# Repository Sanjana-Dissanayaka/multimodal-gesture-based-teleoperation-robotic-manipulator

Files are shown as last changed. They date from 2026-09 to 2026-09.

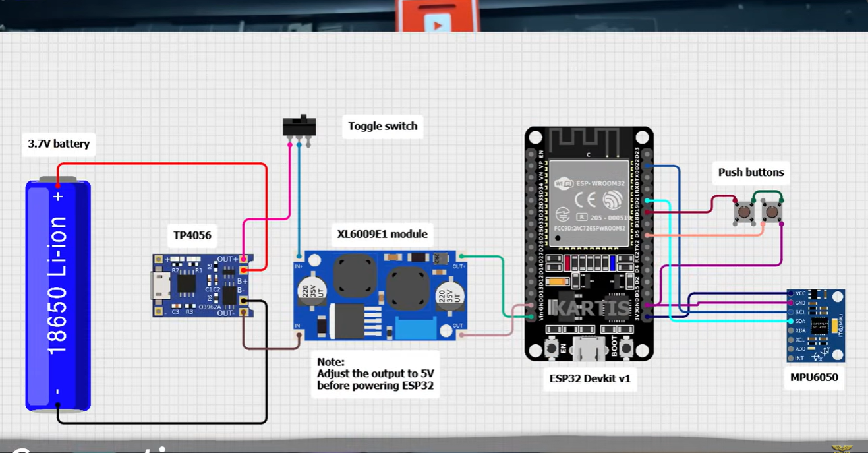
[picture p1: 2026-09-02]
Screenshot 2026-06-09 132017.png

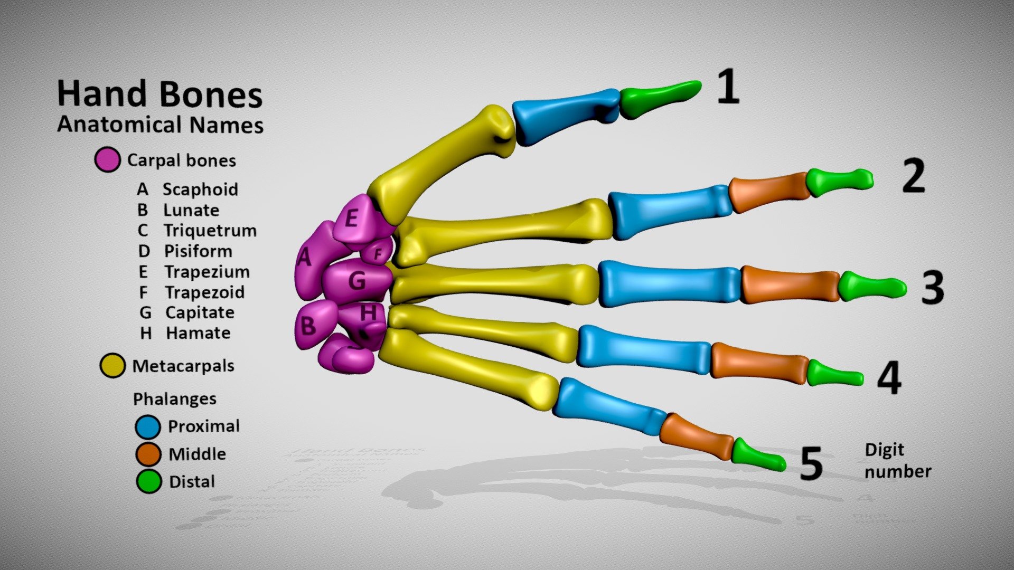
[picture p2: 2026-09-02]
77d40d91b67f4126b4f3d04fdb017b0f.jpeg

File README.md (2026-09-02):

# Multimodal Gesture-Based Teleoperation Framework for Low-Cost Robotic Manipulators

A low-cost gesture-based robotic teleoperation framework designed to provide an intuitive human–robot interaction interface using a wearable sensor glove.

The current system combines an **MPU6050 inertial measurement unit (IMU)** and **flex sensors** with calibration, filtering, gesture recognition, VPython hand visualization, and inverse-kinematics-based robotic manipulator control.

The framework is being extended toward a **hybrid multimodal teleoperation system** by integrating computer-vision-based hand tracking and physical robotic manipulator validation.

---

## Project Overview

Conventional robotic manipulator teleoperation interfaces such as joysticks and teach pendants can be less intuitive when operators need to perform natural hand-based manipulation.

Gesture-based interfaces provide a more natural method of communicating human intent to a robotic system. However, systems that depend on only one sensing method may experience problems such as:

* Sensor drift
* Measurement noise
* Camera occlusion
* Lighting variation
* Limited gesture information
* High implementation cost
* Reduced teleoperation accuracy

This project investigates a low-cost teleoperation framework that initially uses a wearable **IMU + flex-sensor glove** and is designed to later combine wearable sensing with computer vision.

---

## Overall Objective

Develop and validate a low-cost hybrid teleoperation system that integrates an **IMU + flex-sensor glove** with computer-vision-based hand tracking to achieve robust, accurate, and intelligent robotic manipulator control.

---

## System Architecture





The current teleoperation pipeline can be represented as:

```text
Human Hand
    │
    ▼
IMU + Flex Sensor Glove
    │
    ▼
Microcontroller / Data Acquisition
    │
    ▼
Calibration + Filtering
    │
    ▼
Gesture Recognition + Orientation Estimation
    │
    ├──────────────► VPython Virtual Hand
    │
    ▼
Gesture / Orientation Command Mapping
    │
    ▼
Inverse Kinematics
    │
    ▼
Robotic Manipulator Simulation
    │
    ▼
Sorting / Pick-and-Place Tasks
```

The planned multimodal extension is:

```text
Wearable Sensor Glove ──────┐
                            │
                            ▼
                    Hybrid Sensor Fusion
                            ▲
                            │
RGB Camera + MediaPipe ─────┘
                            │
                            ▼
                Robotic Manipulator Control
```

---

## Current Implementation

### 1. Wearable Sensing Layer

The wearable glove provides information about hand orientation and finger movement.

**MPU6050 IMU**

Used to estimate:

* Roll
* Pitch
* Yaw

**Flex Sensors**

Used to detect:

* Finger bending
* Open-hand gestures
* Closed-hand gestures
* Finger-count gestures
* Object-selection commands

---

## 2. Sensor Acquisition and Stabilization



Raw sensor data can contain noise, offsets, and small fluctuations.

The system therefore applies:

* Startup neutral calibration
* Flex-sensor calibration
* IMU calibration
* Deadband processing
* First-order smoothing
* Gesture stabilization
* Threshold-based gesture classification

These techniques improve the stability of commands before they are transmitted to the robotic manipulator.

---

## 3. Flex-Sensor Gesture Validation

The current gesture-validation criteria include:

| Condition | Approximate Threshold |
| --- | ---: |
| Straight finger | ≤ 25° |
| Bent finger | ≥ 60° |
| Stable gesture hold | 0.5 s |

A gesture must remain sufficiently stable before it is accepted as a control command.

This helps prevent accidental commands caused by temporary sensor fluctuations.

---

## 4. Gesture Mapping

Finger gestures are mapped to object-selection and manipulation commands.

| Gesture | Command |
| --- | --- |
| 1 finger  | Select RED object |
| 2 fingers | Select BLUE object |
| 3 fingers | Select GREEN object  |
| 4 fingers | Select YELLOW object |
| Fist | PICK |
| Open palm | PLACE / RELEASE |

This allows the operator to select and manipulate objects using natural hand gestures.

---

## 5. IMU Orientation Mapping

The MPU6050 provides orientation information for controlling the manipulator end effector.

| Human-Hand Motion | Robot Command |
| --- | --- |
| Roll | End-effector roll  |
| Pitch | End-effector pitch |
| Yaw | End-effector yaw |

Control limits are applied to prevent unrealistic or unstable manipulator commands.

### Current Safety Limits

| Motion | Limit |
| --- | ----: |
| Roll |  ±35° |
| Pitch |  ±35° |
| Yaw |  ±60° |
| Command rate | 25 Hz |

---

## 6. Virtual Hand Validation

Before controlling the robotic manipulator, sensor information is visualized using **VPython**.

The virtual-hand environment is used to validate:

* Finger bending
* Hand orientation
* Open-palm detection
* Fist detection
* Finger-count gestures
* Sensor calibration
* Gesture stability

This provides an intermediate validation stage between the physical glove and robotic manipulator.

---

## 7. Robotic Manipulator Simulation

Robotic manipulation is investigated using simulation environments such as:

* PyBullet
* CoppeliaSim

The simulation stage includes:

* Manipulator kinematics
* Forward kinematics
* Inverse kinematics
* End-effector orientation control
* Gesture-to-command mapping
* Object selection
* Pick-and-place operations
* Object sorting
* Contact-based manipulation experiments

---

## Inverse Kinematics

The desired end-effector pose generated from the gesture interface is converted into manipulator joint commands using inverse kinematics.

The general control process is:

```text
Human Gesture
      ↓
Target End-Effector Pose
      ↓
Inverse Kinematics
      ↓
Required Joint Angles
      ↓
Manipulator Motion
```

Inverse kinematics allows intuitive hand commands to be translated into feasible robotic manipulator movements.

---

## Hardware

The project hardware platform includes or investigates:

* MPU6050 IMU
* Flex sensors
* Wearable glove
* Microcontroller
* Custom PCB
* CH340G USB communication interface
* Flex-sensor interface circuitry
* Sensor wiring and connectors
* Robotic manipulator for final physical testing
* RGB camera for the planned vision stage

---

## Software and Development Tools

### Current Tools

* Python
* VPython
* PyBullet
* CoppeliaSim
* Arduino IDE
* KiCad
* Git
* GitHub

### Planned Vision Tools

* OpenCV
* MediaPipe

### Analysis and Evaluation

* Python
* MATLAB

---

## Major Development Phases

### Phase 1 – Wearable Hardware Development

* System architecture development
* PCB design
* Embedded firmware
* Hardware integration

### Phase 2 – Sensor Acquisition and Calibration

* MPU6050 calibration
* Flex-sensor calibration
* Noise filtering
* Gesture stabilization
* Wearable glove fabrication

### Phase 3 – Virtual Hand and Manipulator Validation

* VPython visualization
* Gesture mapping
* Teleoperation data acquisition
* Manipulator simulation
* Inverse-kinematics control

### Phase 4 – Vision-Based Teleoperation

Planned development includes:

* MediaPipe hand tracking
* Vision gesture recognition
* Vision-only manipulator control
* Performance comparison with the sensor glove

### Phase 5 – Hybrid Sensor Fusion

The future multimodal framework will combine:

```text
IMU
 +
Flex Sensors
 +
Computer Vision
        ↓
Hybrid Gesture Estimation
        ↓
Robotic Manipulator Control
```

The aim is to improve robustness against problems such as sensor drift and camera occlusion.

### Phase 6 – Physical Robot Integration

The final stage is intended to include:

* Physical robotic manipulator integration
* Wireless master–slave communication
* Servo-control optimization
* Real-time physical teleoperation
* Pick-and-place experiments
* Robustness testing
* Latency measurement
* Trajectory analysis
* Statistical evaluation

---

## Key Features

* Low-cost wearable gesture interface
* MPU6050-based hand orientation estimation
* Flex-sensor finger-motion measurement
* Sensor calibration
* Deadband processing
* Signal smoothing
* Stable gesture detection
* VPython virtual-hand visualization
* Gesture-labelled object selection
* Inverse-kinematics-based manipulator control
* PyBullet/CoppeliaSim simulation
* Pick-and-place control
* Object sorting
* Extendable multimodal architecture
* Planned MediaPipe computer-vision integration
* Designed for physical robotic-manipulator validation

---

## Research Contribution

The current framework provides a practical foundation for an intuitive and cost-effective human–robot teleoperation interface.

The main research direction is the development of a multimodal system that combines the advantages of wearable sensors and computer vision.

Potential benefits include:

* Improved teleoperation robustness
* Reduced dependence on conventional joysticks
* Natural human–robot interaction
* Improved resistance to camera occlusion
* Compensation for wearable-sensor drift
* Low implementation cost
* Flexible gesture-to-robot mapping

---

---
 ## Project Status

### Completed / Demonstrated

* Wearable gesture-glove prototype
* MPU6050 sensor acquisition
* Flex-sensor acquisition
* Sensor calibration
* Signal smoothing and deadband
* Gesture recognition
* VPython virtual-hand visualization
* Gesture-to-command mapping
* Manipulator simulation
* Inverse-kinematics-based control
* Gesture-controlled sorting and pick-and-place demonstrations

### Next Development Stage

* RGB-camera integration
* MediaPipe hand tracking
* Vision-only teleoperation
* Comparison between glove and vision systems
* Hybrid sensor fusion
* Physical robotic manipulator integration
* Experimental performance evaluation

---

## Future Improvements

* MediaPipe hand-landmark tracking
* Adaptive multimodal sensor fusion
* Vision and wearable-sensor synchronization
* Automatic sensor-drift compensation
* Kalman or complementary filtering
* Improved gesture-classification algorithms
* Wireless glove communication
* Physical 6-DoF manipulator integration
* End-effector camera feedback
* Collision avoidance
* Workspace constraints
* Trajectory smoothing
* Latency optimization
* Gesture confusion-matrix analysis
* Quantitative trajectory-error analysis
* User-based teleoperation experiments

---

## Contributors

### Lowe W.N.D.

**Registration No.: 2022/E/172**

Primary areas include:

* Embedded electronics
* PCB development
* IMU and flex-sensor calibration
* Python development
* Sensor fusion
* Teleoperation implementation
* Experimental evaluation

### Dissanayaka W.A.M.S.K.

**Registration No.: 2022/E/174**

Primary areas include:

* VPython visualization
* PyBullet simulation
* Computer vision
* MediaPipe implementation
* Mechanical fabrication
* Sensor-fusion development
* Experimental evaluation
* Documentation

---

## Supervisors

**Supervisor:** Mr. M. Barathraj
**Co-Supervisor:** Mr. P. Ravivarman

Department of Electrical & Electronic Engineering
Faculty of Engineering
University of Jaffna

---

## License

An open-source license has not yet been specified for this research project.

Because the repository contains collaborative university research work, an appropriate license should be selected only after agreement among the project contributors and relevant supervisors.

---

## Acknowledgements

This project is being developed as part of the undergraduate research work of the **Department of Electrical & Electronic Engineering, Faculty of Engineering, University of Jaffna**.

The authors acknowledge the guidance and support provided by the project supervisor and co-supervisor throughout the development of the gesture-based robotic teleoperation framework.

---

**Project:** Gesture-Based Teleoperation of a Robotic Manipulator
**Research Direction:** Low-Cost Hybrid Gesture-Based Teleoperation Using Wearable Sensor Fusion and Computer Vision

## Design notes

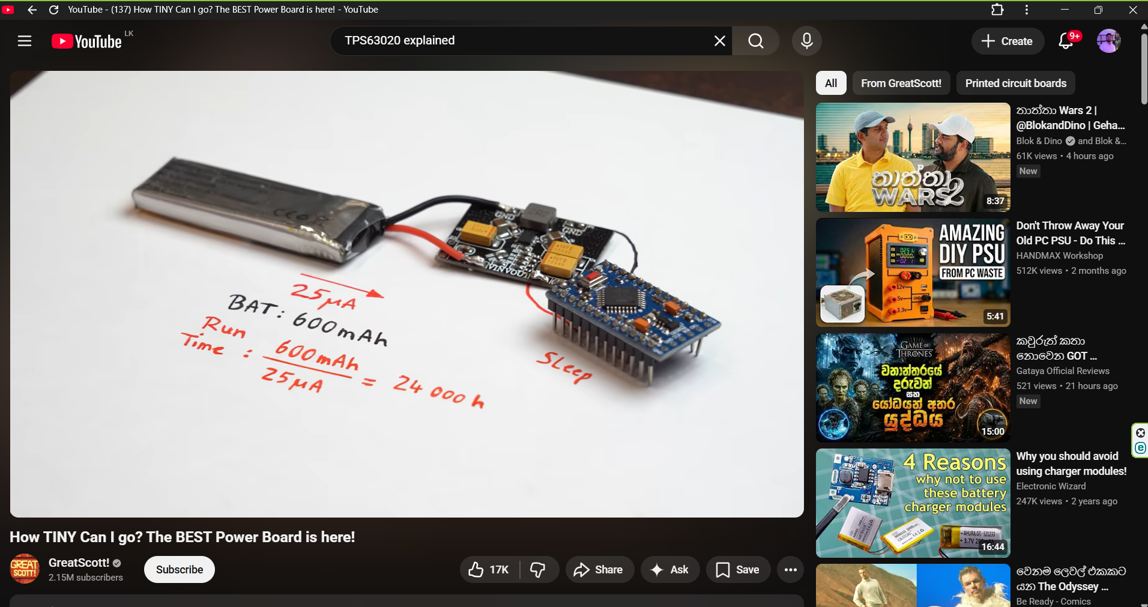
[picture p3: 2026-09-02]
Screenshot 2026-06-09 135950.png

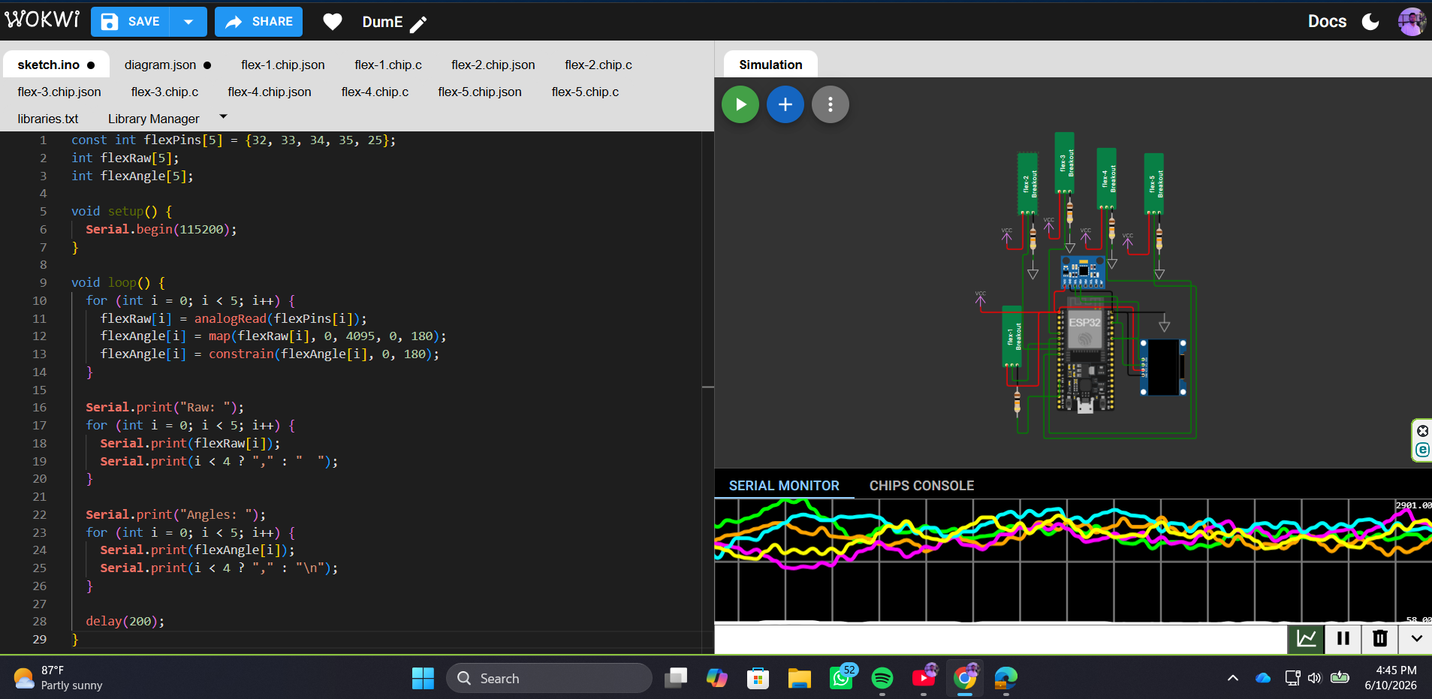
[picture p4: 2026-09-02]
FIVE_FLEX.png

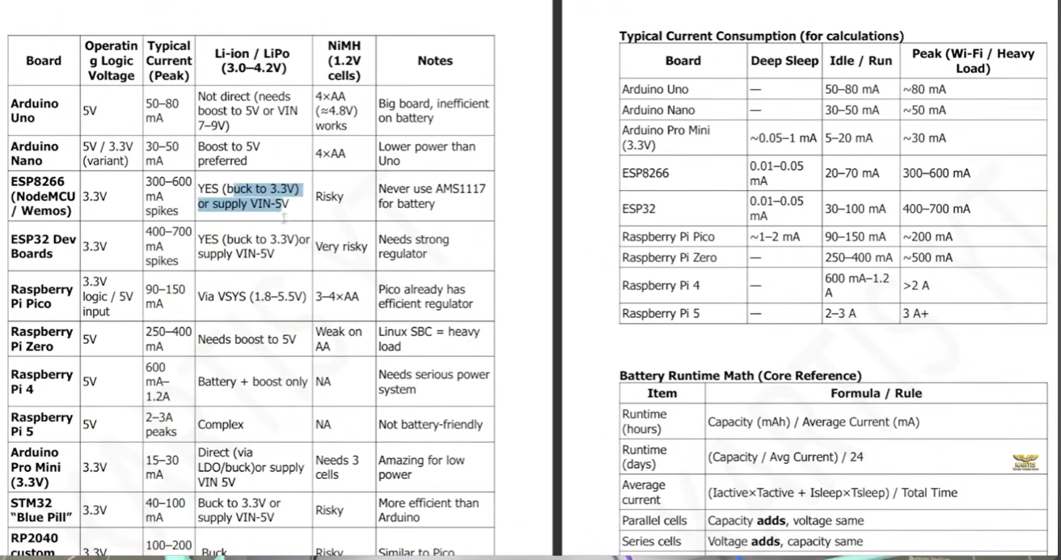
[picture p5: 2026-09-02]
Screenshot 2026-06-09 132211.png

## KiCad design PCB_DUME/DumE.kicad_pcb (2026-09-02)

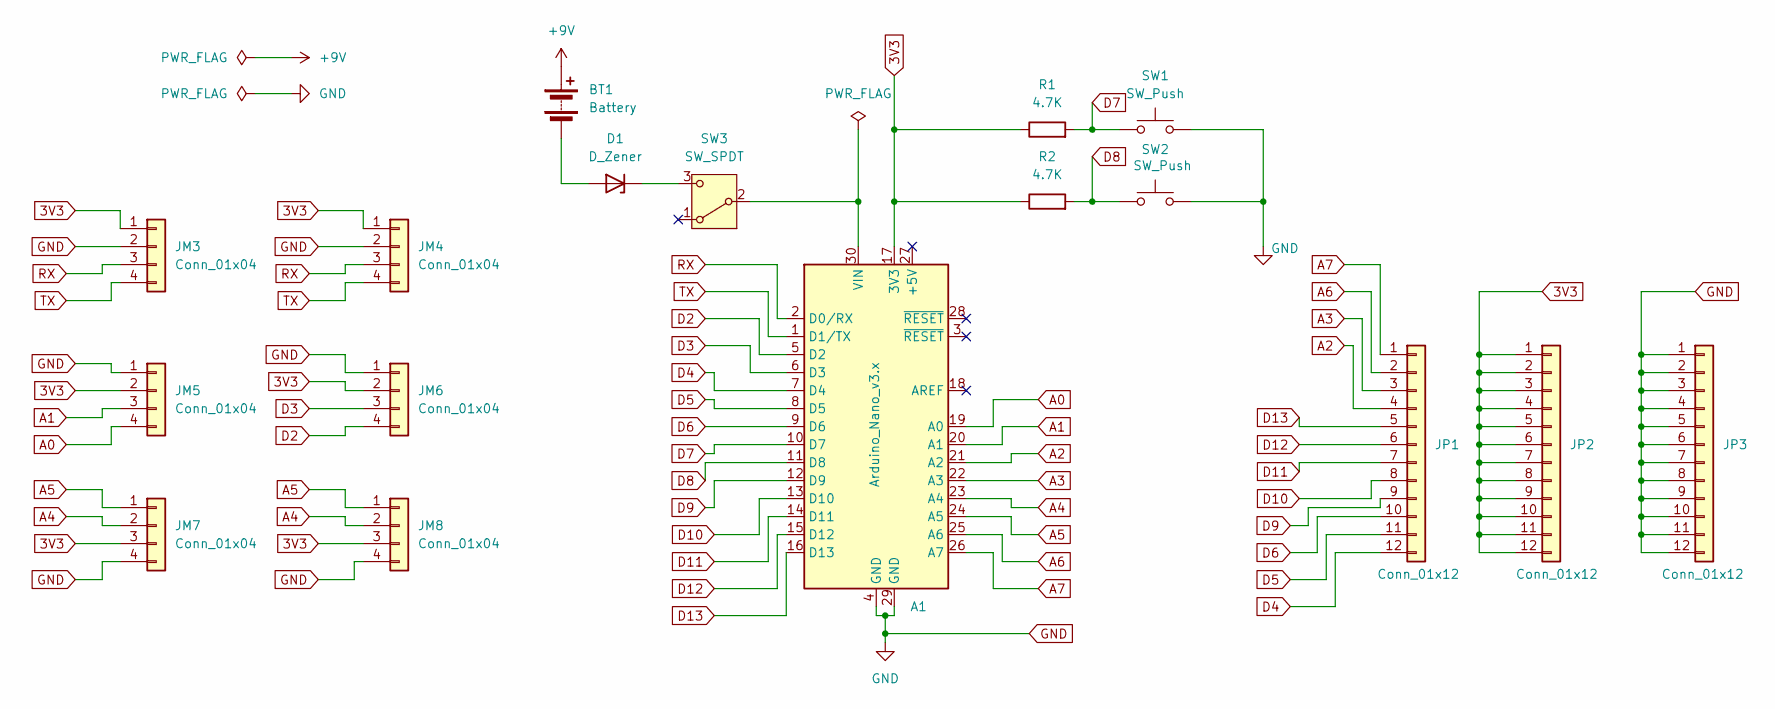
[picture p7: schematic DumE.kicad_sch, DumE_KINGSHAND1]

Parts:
A1: Arduino_Nano_v3.x; Arduino_Nano
BT1: Battery; BatteryHolder_Eagle_12BH611-GR
D1: D_Zener; D_0603_1608Metric
JM3, JM4, JM5, JM6, JM7, JM8: Conn_01x04; PinSocket_1x04_P2.54mm_Vertical
JP1, JP2, JP3: Conn_01x12; PinHeader_1x12_P2.54mm_Vertical
R1, R2: 4.7K; R_0603_1608Metric
SW1, SW2: SW_Push; SW_SPST_CK_RS282G05A3
SW3: SW_SPDT; SW_DIP_SPSTx01_Slide_Copal_CVS-01xB_W5.9mm_P1mm

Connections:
3V3: A1.17 (3V3), JM3.1, JM4.1, JM5.2, JM6.2, JM7.3, JM8.3, JP2.1, JP2.2, JP2.3, JP2.4, JP2.5, JP2.6, JP2.7, JP2.8, JP2.9, JP2.10, JP2.11, JP2.12, R1.1, R2.1
+9V: BT1.1 (+)
A0: A1.19 (A0), JM5.4
A1: A1.20 (A1), JM5.3
A2: A1.21 (A2), JP1.4
A3: A1.22 (A3), JP1.3
A4: A1.23 (A4), JM7.2, JM8.2
A5: A1.24 (A5), JM7.1, JM8.1
A6: A1.25 (A6), JP1.2
A7: A1.26 (A7), JP1.1
D2: A1.5 (D2), JM6.4
D3: A1.6 (D3), JM6.3
D4: A1.7 (D4), JP1.12
D5: A1.8 (D5), JP1.11
D6: A1.9 (D6), JP1.10
D7: A1.10 (D7), R1.2, SW1.1
D8: A1.11 (D8), R2.2, SW2.1
D9: A1.12 (D9), JP1.9
D10: A1.13 (D10), JP1.8
D11: A1.14 (D11), JP1.7
D12: A1.15 (D12), JP1.6
D13: A1.16 (D13), JP1.5
GND: A1.4 (GND), A1.29 (GND), JM3.2, JM4.2, JM5.1, JM6.1, JM7.4, JM8.4, JP3.1, JP3.2, JP3.3, JP3.4, JP3.5, JP3.6, JP3.7, JP3.8, JP3.9, JP3.10, JP3.11, JP3.12, SW1.2, SW2.2
unnamed: A1.30 (VIN), SW3.2 (B)
unnamed: BT1.2 (-), D1.2 (A)
unnamed: D1.1 (K), SW3.3 (C)
RX: A1.2 (D0/RX), JM3.3, JM4.3
TX: A1.1 (D1/TX), JM3.4, JM4.4

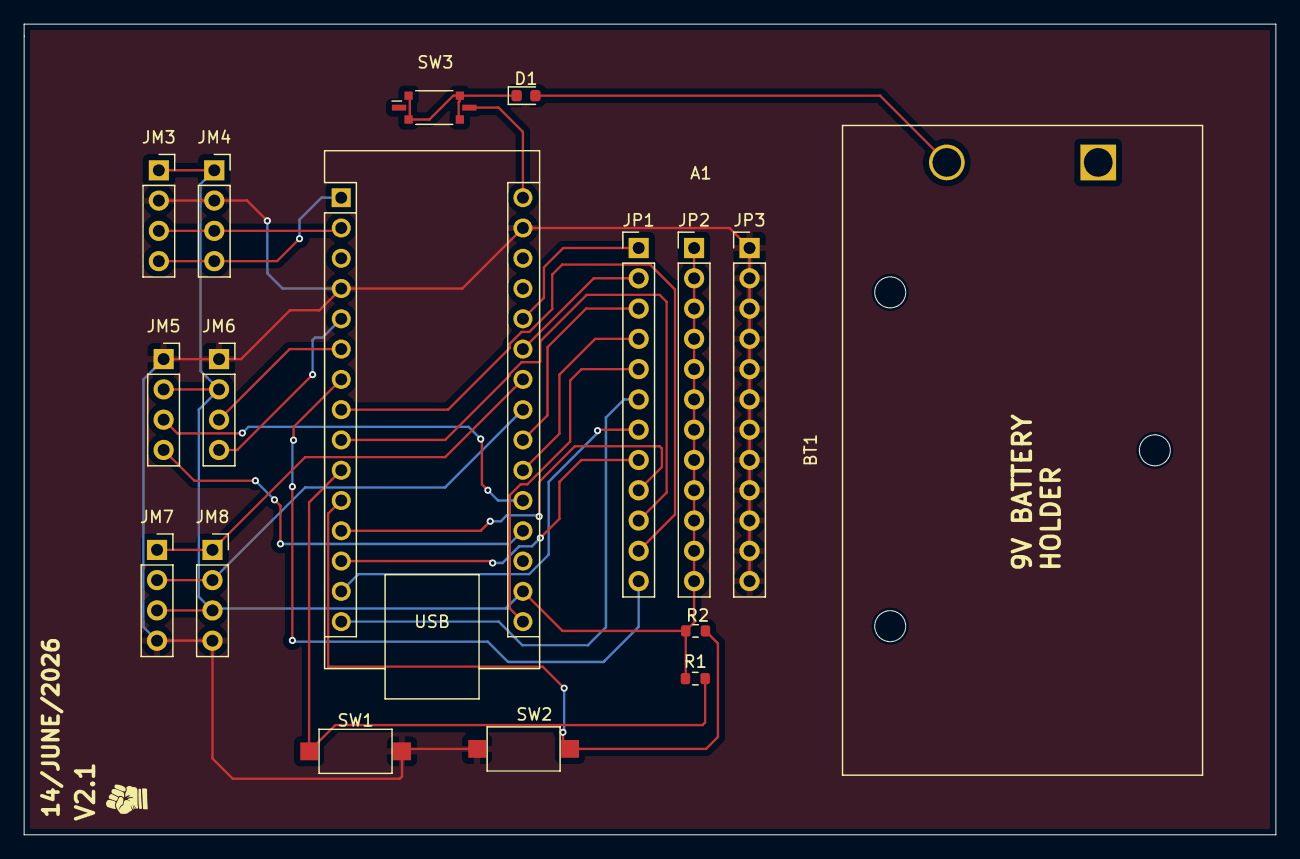
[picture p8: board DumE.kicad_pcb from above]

Board: 2 copper layers, 105.0 x 68.0 mm, 17 parts (0 on the bottom side), 27 nets.

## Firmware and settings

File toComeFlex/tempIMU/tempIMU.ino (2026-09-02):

#include <Adafruit_MPU6050.h>
#include <Adafruit_Sensor.h>
#include <Wire.h>
#include <math.h>

// =====================================================
// USER SETTINGS
// =====================================================

const int YAW_RESET_PIN = 8;

// IMU calculation frequency
const unsigned long IMU_PERIOD_US = 5000;   // 200 Hz

// Serial transmission frequency
const unsigned long OUTPUT_PERIOD_MS = 25;  // 40 Hz

// true  = Arduino Serial Plotter format
// false = CSV format for future Python/sensor fusion
const bool SERIAL_PLOTTER_MODE = true;

// Complementary-filter time constant
// Larger = smoother, but slower accelerometer correction
const float COMPLEMENTARY_TAU = 0.40f;

// Enable slow gyro-bias correction while stationary
const bool ENABLE_ONLINE_GYRO_BIAS = true;

// Bias adjustment time constant
const float GYRO_BIAS_TAU = 20.0f;

// Standard gravitational acceleration
const float GRAVITY = 9.80665f;


// =====================================================
// ACCELEROMETER CALIBRATION VALUES
// =====================================================

// Keep your previously measured calibration values.
// The Y-axis calibration should preferably be verified again.

const float xMax = 1.05f;
const float xMin = -1.01f;

const float yMax = 0.38f;
const float yMin = -1.68f;

const float zMax = 1.00f;
const float zMin = -1.07f;

const float xOffset = (xMax + xMin) / 2.0f;
const float yOffset = (yMax + yMin) / 2.0f;
const float zOffset = (zMax + zMin) / 2.0f;

const float xScale = 2.0f / (xMax - xMin);
const float yScale = 2.0f / (yMax - yMin);
const float zScale = 2.0f / (zMax - zMin);


// =====================================================
// MPU6050 OBJECT
// =====================================================

Adafruit_MPU6050 mpu;


// =====================================================
// SENSOR VARIABLES
// =====================================================

// Calibrated accelerometer values in g
float Ax = 0.0f;
float Ay = 0.0f;
float Az = 0.0f;

// Gyroscope rates in degrees per second
float gyroRollRate = 0.0f;
float gyroPitchRate = 0.0f;
float gyroYawRate = 0.0f;

// Accelerometer-based orientation
float rollAcc = 0.0f;
float pitchAcc = 0.0f;

// Complementary-filter orientation
float rollComp = 0.0f;
float pitchComp = 0.0f;

// Relative yaw angle
float yawG = 0.0f;

// Acceleration information
float accelerationMagnitude = 1.0f;
float accelerometerTrust = 1.0f;


// =====================================================
// GYROSCOPE CALIBRATION
// =====================================================

// Offsets are stored in radians per second because
// Adafruit MPU6050 returns gyroscope measurements in rad/s.

float gyroXOffset = 0.0f;
float gyroYOffset = 0.0f;
float gyroZOffset = 0.0f;


// =====================================================
// TIMING
// =====================================================

unsigned long previousImuTimeUs = 0;
unsigned long previousOutputTimeMs = 0;


// =====================================================
// STATIONARY DETECTION
// =====================================================

bool imuStationary = false;
float stationaryDuration = 0.0f;

// Sensor is considered stationary when acceleration
// is close to 1 g and angular velocity is very small.

const float STATIONARY_ACCEL_ERROR = 0.08f;
const float STATIONARY_GYRO_LIMIT = 0.75f;
const float STATIONARY_REQUIRED_TIME = 1.0f;


// =====================================================
// BUTTON DEBOUNCE
// =====================================================

bool lastRawButtonState = HIGH;
bool stableButtonState = HIGH;

unsigned long buttonChangeTimeMs = 0;
const unsigned long DEBOUNCE_TIME_MS = 30;


// =====================================================
// FUNCTION DECLARATIONS
// =====================================================

void calibrateGyroscope();
void initializeOrientation();
void updateImu(float dt);
void updateStationaryBias(
  float rawGx,
  float rawGy,
  float rawGz,
  float dt
);

void handleYawResetButton();
void printImuData();

float calculateAccelerometerTrust(float magnitude);
float wrapAngle180(float angle);


// =====================================================
// SETUP
// =====================================================

void setup() {
  Serial.begin(115200);

  Wire.begin();

  // Faster I2C communication for more consistent timing
  Wire.setClock(400000);

  pinMode(YAW_RESET_PIN, INPUT_PULLUP);

  Serial.println("Starting MPU6050...");

  if (!mpu.begin()) {
    Serial.println("MPU6050 not detected.");

    while (true) {
      delay(500);
    }
  }

  Serial.println("MPU6050 detected.");

  // Highest accelerometer precision
  mpu.setAccelerometerRange(MPU6050_RANGE_2_G);

  // Better gyro resolution than the original ±2000 deg/s
  mpu.setGyroRange(MPU6050_RANGE_500_DEG);

  // Internal digital low-pass filter
  mpu.setFilterBandwidth(MPU6050_BAND_21_HZ);

  // Allow the sensor to stabilize thermally
  Serial.println("Keep the IMU completely stationary...");
  delay(1500);

  calibrateGyroscope();
  initializeOrientation();

  previousImuTimeUs = micros();
  previousOutputTimeMs = millis();

  Serial.println("IMU ready.");
}


// =====================================================
// MAIN LOOP
// =====================================================

void loop() {
  handleYawResetButton();

  unsigned long currentTimeUs = micros();

  if (
    (unsigned long)(currentTimeUs - previousImuTimeUs)
    >= IMU_PERIOD_US
  ) {
    float dt =
      (currentTimeUs - previousImuTimeUs) * 0.000001f;

    previousImuTimeUs = currentTimeUs;

    /*
      Prevent an unusually long interruption from causing
      a large false integrated angle.
    */
    if (dt <= 0.0f || dt > 0.020f) {
      dt = IMU_PERIOD_US * 0.000001f;
    }

    updateImu(dt);
  }

  unsigned long currentTimeMs = millis();

  if (
    (unsigned long)(currentTimeMs - previousOutputTimeMs)
    >= OUTPUT_PERIOD_MS
  ) {
    previousOutputTimeMs = currentTimeMs;
    printImuData();
  }
}


// =====================================================
// INITIAL GYROSCOPE CALIBRATION
// =====================================================

void calibrateGyroscope() {
  const int CALIBRATION_SAMPLES = 1000;

  double sumX = 0.0;
  double sumY = 0.0;
  double sumZ = 0.0;

  double squareSumX = 0.0;
  double squareSumY = 0.0;
  double squareSumZ = 0.0;

  Serial.println("Calibrating gyroscope...");
  Serial.println("Do not move the sensor.");

  // Discard initial readings
  for (int i = 0; i < 100; i++) {
    sensors_event_t acceleration;
    sensors_event_t gyro;
    sensors_event_t temperature;

    mpu.getEvent(
      &acceleration,
      &gyro,
      &temperature
    );

    delay(2);
  }

  for (int i = 0; i < CALIBRATION_SAMPLES; i++) {
    sensors_event_t acceleration;
    sensors_event_t gyro;
    sensors_event_t temperature;

    mpu.getEvent(
      &acceleration,
      &gyro,
      &temperature
    );

    sumX += gyro.gyro.x;
    sumY += gyro.gyro.y;
    sumZ += gyro.gyro.z;

    squareSumX += gyro.gyro.x * gyro.gyro.x;
    squareSumY += gyro.gyro.y * gyro.gyro.y;
    squareSumZ += gyro.gyro.z * gyro.gyro.z;

    delay(2);
  }

  gyroXOffset = sumX / CALIBRATION_SAMPLES;
  gyroYOffset = sumY / CALIBRATION_SAMPLES;
  gyroZOffset = sumZ / CALIBRATION_SAMPLES;

  float varianceX =
    (squareSumX / CALIBRATION_SAMPLES)
    - (gyroXOffset * gyroXOffset);

  float varianceY =
    (squareSumY / CALIBRATION_SAMPLES)
    - (gyroYOffset * gyroYOffset);

  float varianceZ =
    (squareSumZ / CALIBRATION_SAMPLES)
    - (gyroZOffset * gyroZOffset);

  if (varianceX < 0.0f) varianceX = 0.0f;
  if (varianceY < 0.0f) varianceY = 0.0f;
  if (varianceZ < 0.0f) varianceZ = 0.0f;

  float standardDeviationX =
    sqrt(varianceX) * RAD_TO_DEG;

  float standardDeviationY =
    sqrt(varianceY) * RAD_TO_DEG;

  float standardDeviationZ =
    sqrt(varianceZ) * RAD_TO_DEG;

  Serial.println("Gyroscope calibration completed.");

  Serial.print("X offset (rad/s): ");
  Serial.println(gyroXOffset, 6);

  Serial.print("Y offset (rad/s): ");
  Serial.println(gyroYOffset, 6);

  Serial.print("Z offset (rad/s): ");
  Serial.println(gyroZOffset, 6);

  Serial.print("X noise standard deviation (deg/s): ");
  Serial.println(standardDeviationX, 4);

  Serial.print("Y noise standard deviation (deg/s): ");
  Serial.println(standardDeviationY, 4);

  Serial.print("Z noise standard deviation (deg/s): ");
  Serial.println(standardDeviationZ, 4);

  if (
    standardDeviationX > 0.8f ||
    standardDeviationY > 0.8f ||
    standardDeviationZ > 0.8f
  ) {
    Serial.println(
      "Warning: Movement may have occurred during calibration."
    );
  }
}


// =====================================================
// INITIAL ORIENTATION
// =====================================================

void initializeOrientation() {
  const int INITIAL_SAMPLES = 200;

  float sumAx = 0.0f;
  float sumAy = 0.0f;
  float sumAz = 0.0f;

  Serial.println("Initializing roll and pitch...");

  for (int i = 0; i < INITIAL_SAMPLES; i++) {
    sensors_event_t acceleration;
    sensors_event_t gyro;
    sensors_event_t temperature;

    mpu.getEvent(
      &acceleration,
      &gyro,
      &temperature
    );

    float rawAx = acceleration.acceleration.x / GRAVITY;
    float rawAy = acceleration.acceleration.y / GRAVITY;
    float rawAz = acceleration.acceleration.z / GRAVITY;

    float calibratedAx = xScale * (rawAx - xOffset);
    float calibratedAy = yScale * (rawAy - yOffset);
    float calibratedAz = zScale * (rawAz - zOffset);

    sumAx += calibratedAx;
    sumAy += calibratedAy;
    sumAz += calibratedAz;

    delay(5);
  }

  Ax = sumAx / INITIAL_SAMPLES;
  Ay = sumAy / INITIAL_SAMPLES;
  Az = sumAz / INITIAL_SAMPLES;

  /*
    These equations preserve the axis convention
    used in your original program.
  */
  pitchAcc =
    atan2(
      Ay,
      sqrt((Az * Az) + (Ax * Ax))
    ) * RAD_TO_DEG;

  rollAcc =
    atan2(
      Ax,
      sqrt((Az * Az) + (Ay * Ay))
    ) * RAD_TO_DEG;

  rollComp = rollAcc;
  pitchComp = pitchAcc;
  yawG = 0.0f;

  Serial.print("Initial roll: ");
  Serial.println(rollComp, 2);

  Serial.print("Initial pitch: ");
  Serial.println(pitchComp, 2);
}


// =====================================================
// IMU UPDATE
// =====================================================

void updateImu(float dt) {
  sensors_event_t acceleration;
  sensors_event_t gyro;
  sensors_event_t temperature;

  mpu.getEvent(
    &acceleration,
    &gyro,
    &temperature
  );

  // Convert acceleration from m/s^2 to g
  float rawAx = acceleration.acceleration.x / GRAVITY;
  float rawAy = acceleration.acceleration.y / GRAVITY;
  float rawAz = acceleration.acceleration.z / GRAVITY;

  // Apply accelerometer offset and scale correction
  Ax = xScale * (rawAx - xOffset);
  Ay = yScale * (rawAy - yOffset);
  Az = zScale * (rawAz - zOffset);

  accelerationMagnitude =
    sqrt((Ax * Ax) + (Ay * Ay) + (Az * Az));

  // Residual gyro values after bias removal
  float correctedGx =
    gyro.gyro.x - gyroXOffset;

  float correctedGy =
    gyro.gyro.y - gyroYOffset;

  float correctedGz =
    gyro.gyro.z - gyroZOffset;

  /*
    Preserve your original gyro orientation:

      Roll  uses negative Y gyro.
      Pitch uses positive X gyro.
      Yaw   uses positive Z gyro.
  */
  gyroRollRate =
    -correctedGy * RAD_TO_DEG;

  gyroPitchRate =
    correctedGx * RAD_TO_DEG;

  gyroYawRate =
    correctedGz * RAD_TO_DEG;

  updateStationaryBias(
    gyro.gyro.x,
    gyro.gyro.y,
    gyro.gyro.z,
    dt
  );

  /*
    Recalculate gyro rates because the online bias
    may have been updated.
  */
  correctedGx =
    gyro.gyro.x - gyroXOffset;

  correctedGy =
    gyro.gyro.y - gyroYOffset;

  correctedGz =
    gyro.gyro.z - gyroZOffset;

  gyroRollRate =
    -correctedGy * RAD_TO_DEG;

  gyroPitchRate =
    correctedGx * RAD_TO_DEG;

  gyroYawRate =
    correctedGz * RAD_TO_DEG;

  // Accelerometer orientation
  pitchAcc =
    atan2(
      Ay,
      sqrt((Az * Az) + (Ax * Ax))
    ) * RAD_TO_DEG;

  rollAcc =
    atan2(
      Ax,
      sqrt((Az * Az) + (Ay * Ay))
    ) * RAD_TO_DEG;

  /*
    Time-dependent complementary-filter coefficient.

    At dt = 0.005 s and tau = 0.40 s:
    alpha is approximately 0.988.
  */
  float alpha =
    COMPLEMENTARY_TAU /
    (COMPLEMENTARY_TAU + dt);

  accelerometerTrust =
    calculateAccelerometerTrust(
      accelerationMagnitude
    );

  /*
    Reduce accelerometer correction when the hand is
    undergoing significant linear acceleration.
  */
  float accelerometerCorrection =
    (1.0f - alpha) * accelerometerTrust;

  // Gyroscope prediction
  float predictedRoll =
    rollComp + (gyroRollRate * dt);

  float predictedPitch =
    pitchComp + (gyroPitchRate * dt);

  // Adaptive complementary correction
  float rollError =
    wrapAngle180(rollAcc - predictedRoll);

  float pitchError =
    wrapAngle180(pitchAcc - predictedPitch);

  rollComp =
    predictedRoll
    + (accelerometerCorrection * rollError);

  pitchComp =
    predictedPitch
    + (accelerometerCorrection * pitchError);

  // Relative yaw from gyro only
  yawG += gyroYawRate * dt;
}


// =====================================================
// ONLINE GYRO-BIAS CORRECTION
// =====================================================

void updateStationaryBias(
  float rawGx,
  float rawGy,
  float rawGz,
  float dt
) {
  float correctedGx =
    (rawGx - gyroXOffset) * RAD_TO_DEG;

  float correctedGy =
    (rawGy - gyroYOffset) * RAD_TO_DEG;

  float correctedGz =
    (rawGz - gyroZOffset) * RAD_TO_DEG;

  float totalAngularRate =
    sqrt(
      (correctedGx * correctedGx)
      + (correctedGy * correctedGy)
      + (correctedGz * correctedGz)
    );

  bool accelerationIsStable =
    fabs(accelerationMagnitude - 1.0f)
    < STATIONARY_ACCEL_ERROR;

  bool gyroIsStable =
    totalAngularRate
    < STATIONARY_GYRO_LIMIT;

  if (accelerationIsStable && gyroIsStable) {
    stationaryDuration += dt;
  } else {
    stationaryDuration = 0.0f;
  }

  imuStationary =
    stationaryDuration >= STATIONARY_REQUIRED_TIME;

  if (
    ENABLE_ONLINE_GYRO_BIAS &&
    imuStationary
  ) {
    /*
      Slowly move the bias toward the current stationary
      gyro reading. This reduces temperature-related drift.
    */
    float beta =
      dt / (GYRO_BIAS_TAU + dt);

    gyroXOffset +=
      beta * (rawGx - gyroXOffset);

    gyroYOffset +=
      beta * (rawGy - gyroYOffset);

    gyroZOffset +=
      beta * (rawGz - gyroZOffset);
  }
}


// =====================================================
// ACCELEROMETER TRUST
// =====================================================

float calculateAccelerometerTrust(float magnitude) {
  float error = fabs(magnitude - 1.0f);

  /*
    Full accelerometer trust:
      acceleration magnitude within ±0.08 g

    Zero accelerometer trust:
      acceleration differs by at least 0.30 g
  */
  const float FULL_TRUST_ERROR = 0.08f;
  const float ZERO_TRUST_ERROR = 0.30f;

  if (error <= FULL_TRUST_ERROR) {
    return 1.0f;
  }

  if (error >= ZERO_TRUST_ERROR) {
    return 0.0f;
  }

  return 1.0f -
    (
      (error - FULL_TRUST_ERROR) /
      (ZERO_TRUST_ERROR - FULL_TRUST_ERROR)
    );
}


// =====================================================
// NON-BLOCKING YAW RESET BUTTON
// =====================================================

void handleYawResetButton() {
  bool rawButtonState =
    digitalRead(YAW_RESET_PIN);

  if (rawButtonState != lastRawButtonState) {
    buttonChangeTimeMs = millis();
    lastRawButtonState = rawButtonState;
  }

  if (
    millis() - buttonChangeTimeMs
    >= DEBOUNCE_TIME_MS
  ) {
    if (rawButtonState != stableButtonState) {
      stableButtonState = rawButtonState;

      // Button has just been pressed
      if (stableButtonState == LOW) {
        yawG = 0.0f;
      }
    }
  }
}


// =====================================================
// SERIAL OUTPUT
// =====================================================

void printImuData() {
  if (SERIAL_PLOTTER_MODE) {
    Serial.print("rollComp:");
    Serial.print(rollComp, 2);
    Serial.print(',');

    Serial.print("pitchComp:");
    Serial.print(pitchComp, 2);
    Serial.print(',');

    Serial.print("yawG:");
    Serial.print(yawG, 2);
    Serial.print(',');

    Serial.print("accMagnitude:");
    Serial.print(accelerationMagnitude, 3);
    Serial.print(',');

    Serial.print("accTrust:");
    Serial.print(accelerometerTrust * 100.0f, 1);
    Serial.print(',');

    Serial.print("stationary:");
    Serial.print(imuStationary ? 20 : 0);
    Serial.print(',');

    Serial.print("UL:");
    Serial.print(90);
    Serial.print(',');

    Serial.print("LL:");
    Serial.println(-90);
  } else {
    /*
      Future Python/sensor-fusion CSV format:

      IMU,
      roll,
      pitch,
      yaw,
      rollRate,
      pitchRate,
      yawRate,
      Ax,
      Ay,
      Az,
      accelerationMagnitude,
      accelerometerTrust,
      stationary
    */

    Serial.print("IMU,");
    Serial.print(rollComp, 3);
    Serial.print(',');

    Serial.print(pitchComp, 3);
    Serial.print(',');

    Serial.print(yawG, 3);
    Serial.print(',');

    Serial.print(gyroRollRate, 3);
    Serial.print(',');

    Serial.print(gyroPitchRate, 3);
    Serial.print(',');

    Serial.print(gyroYawRate, 3);
    Serial.print(',');

    Serial.print(Ax, 4);
    Serial.print(',');

    Serial.print(Ay, 4);
    Serial.print(',');

    Serial.print(Az, 4);
    Serial.print(',');

    Serial.print(accelerationMagnitude, 4);
    Serial.print(',');

    Serial.print(accelerometerTrust, 3);
    Serial.print(',');

    Serial.println(imuStationary ? 1 : 0);
  }
}


// =====================================================
// ANGLE WRAPPING
// =====================================================

float wrapAngle180(float angle) {
  while (angle > 180.0f) {
    angle -= 360.0f;
  }

  while (angle < -180.0f) {
    angle += 360.0f;
  }

  return angle;
}

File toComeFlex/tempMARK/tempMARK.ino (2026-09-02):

#include <Adafruit_MPU6050.h>
#include <Adafruit_Sensor.h>
#include <Wire.h>
#include <math.h>

// =====================================================
// HARDWARE CONFIGURATION
// =====================================================

const int FLEX_SENSOR_PIN = A2;
const int YAW_RESET_PIN = 8;

Adafruit_MPU6050 mpu;

// IMU processing at 200 Hz
const unsigned long IMU_PERIOD_US = 5000;

// Serial output at 20 Hz
const unsigned long OUTPUT_PERIOD_MS = 50;

// =====================================================
// FLEX-SENSOR CALIBRATION
// =====================================================

const int FLEX_FLAT = 5;
const int FLEX_HALF_BENT = 73;
const int FLEX_FULLY_BENT = 127;

// EMA smoothing factor
const float FLEX_ALPHA = 0.15f;

// Prevent state flickering near thresholds
const float FLEX_HYSTERESIS = 3.0f;

float filteredFlexValue = 0.0f;
float bendPercentage = 0.0f;
bool flexFilterInitialized = false;

int rawFlexValue = 0;

// =====================================================
// FLEX STATES
// =====================================================

enum FingerState {
  FINGER_FLAT,
  FINGER_SLIGHT_BEND,
  FINGER_HALF_BENT,
  FINGER_BENT,
  FINGER_FULLY_BENT
};

FingerState currentFingerState = FINGER_FLAT;

const float FLEX_STATE_THRESHOLDS[4] = {
  20.0f,
  40.0f,
  65.0f,
  85.0f
};

// =====================================================
// ACCELEROMETER CALIBRATION
// =====================================================

const float GRAVITY = 9.80665f;

const float xMax = 1.05f;
const float xMin = -1.01f;

const float yMax = 0.38f;
const float yMin = -1.68f;

const float zMax = 1.00f;
const float zMin = -1.07f;

const float xOffset = (xMax + xMin) / 2.0f;
const float yOffset = (yMax + yMin) / 2.0f;
const float zOffset = (zMax + zMin) / 2.0f;

const float xScale = 2.0f / (xMax - xMin);
const float yScale = 2.0f / (yMax - yMin);
const float zScale = 2.0f / (zMax - zMin);

// =====================================================
// IMU VARIABLES
// =====================================================

float Ax = 0.0f;
float Ay = 0.0f;
float Az = 0.0f;

float gyroXOffset = 0.0f;
float gyroYOffset = 0.0f;
float gyroZOffset = 0.0f;

float gyroRollRate = 0.0f;
float gyroPitchRate = 0.0f;
float gyroYawRate = 0.0f;

float rollAcc = 0.0f;
float pitchAcc = 0.0f;

float rollComp = 0.0f;
float pitchComp = 0.0f;
float yawG = 0.0f;

float accelerationMagnitude = 1.0f;
float accelerometerTrust = 1.0f;

const float COMPLEMENTARY_TAU = 0.40f;

// =====================================================
// STATIONARY DETECTION AND BIAS CORRECTION
// =====================================================

bool imuStationary = false;
float stationaryDuration = 0.0f;

const float STATIONARY_ACCEL_ERROR = 0.08f;
const float STATIONARY_GYRO_LIMIT = 0.75f;
const float STATIONARY_REQUIRED_TIME = 1.0f;

const float GYRO_BIAS_TAU = 20.0f;

// =====================================================
// PALM ORIENTATION STATES
// =====================================================

enum PalmState {
  PALM_LEVEL,
  PALM_LEFT,
  PALM_RIGHT,
  PALM_FORWARD,
  PALM_BACK
};

PalmState currentPalmState = PALM_LEVEL;

// A palm tilt must exceed 25 degrees to enter a tilt state.
const float PALM_ENTRY_ANGLE = 25.0f;

// It returns to level below approximately 18 degrees.
const float PALM_EXIT_ANGLE = 18.0f;

// =====================================================
// MOTION STATES
// =====================================================

enum MotionState {
  MOTION_STILL,
  MOTION_MOVING,
  MOTION_YAW_POSITIVE,
  MOTION_YAW_NEGATIVE
};

MotionState currentMotionState = MOTION_STILL;

const float GENERAL_MOTION_THRESHOLD = 45.0f;
const float YAW_MOTION_THRESHOLD = 90.0f;

unsigned long motionHoldUntilMs = 0;

// =====================================================
// TIMING
// =====================================================

unsigned long previousImuTimeUs = 0;
unsigned long previousOutputTimeMs = 0;

// =====================================================
// YAW RESET BUTTON
// =====================================================

bool lastRawButtonState = HIGH;
bool stableButtonState = HIGH;

unsigned long buttonChangeTimeMs = 0;
const unsigned long DEBOUNCE_TIME_MS = 30;

// =====================================================
// SETUP
// =====================================================

void setup() {
  Serial.begin(115200);

  Wire.begin();
  Wire.setClock(400000);

  pinMode(FLEX_SENSOR_PIN, INPUT);
  pinMode(YAW_RESET_PIN, INPUT_PULLUP);

  Serial.println("Starting fused flex and IMU system...");

  if (!mpu.begin()) {
    Serial.println("MPU6050 not detected.");

    while (true) {
      delay(500);
    }
  }

  mpu.setAccelerometerRange(MPU6050_RANGE_2_G);
  mpu.setGyroRange(MPU6050_RANGE_500_DEG);
  mpu.setFilterBandwidth(MPU6050_BAND_21_HZ);

  Serial.println("Keep the glove completely stationary.");
  delay(1500);

  calibrateGyroscope();
  initializeOrientation();
  initializeFlexSensor();

  previousImuTimeUs = micros();
  previousOutputTimeMs = millis();

  Serial.println("Fused gesture system ready.");
}

// =====================================================
// MAIN LOOP
// =====================================================

void loop() {
  handleYawResetButton();

  unsigned long currentTimeUs = micros();

  if (
    (unsigned long)(currentTimeUs - previousImuTimeUs)
    >= IMU_PERIOD_US
  ) {
    float dt =
      (currentTimeUs - previousImuTimeUs) * 0.000001f;

    previousImuTimeUs = currentTimeUs;

    // Reject abnormal timing intervals
    if (dt <= 0.0f || dt > 0.020f) {
      dt = IMU_PERIOD_US * 0.000001f;
    }

    updateFlexSensor();
    updateImu(dt);

    updateFingerState(bendPercentage);
    updatePalmState();
    updateMotionState();
  }

  unsigned long currentTimeMs = millis();

  if (
    (unsigned long)(currentTimeMs - previousOutputTimeMs)
    >= OUTPUT_PERIOD_MS
  ) {
    previousOutputTimeMs = currentTimeMs;

    sendFusionData();
  }
}

// =====================================================
// FLEX SENSOR
// =====================================================

void initializeFlexSensor() {
  long total = 0;

  for (int i = 0; i < 100; i++) {
    total += analogRead(FLEX_SENSOR_PIN);
    delay(2);
  }

  filteredFlexValue = total / 100.0f;
  flexFilterInitialized = true;
}

void updateFlexSensor() {
  rawFlexValue = analogRead(FLEX_SENSOR_PIN);

  int medianValue = readFlexMedianOfFive();

  if (!flexFilterInitialized) {
    filteredFlexValue = medianValue;
    flexFilterInitialized = true;
  }

  // Exponential Moving Average filter
  filteredFlexValue =
    (FLEX_ALPHA * medianValue)
    + ((1.0f - FLEX_ALPHA) * filteredFlexValue);

  bendPercentage =
    flexValueToPercentage(filteredFlexValue);
}
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
